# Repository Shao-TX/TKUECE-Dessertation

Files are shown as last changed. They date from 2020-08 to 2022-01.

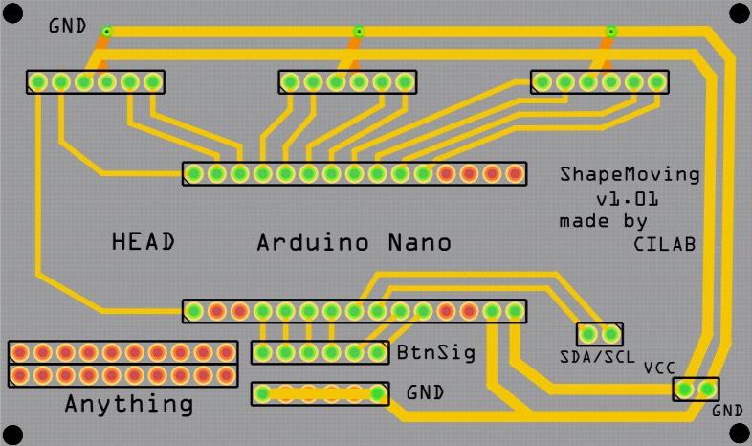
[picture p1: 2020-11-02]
hardware/PCB/Image/PCB_Image.jpg

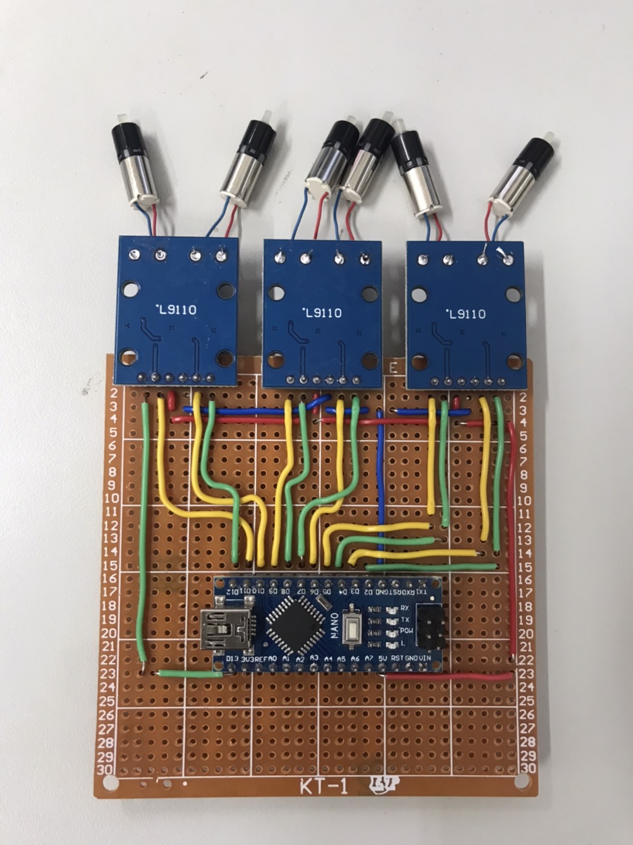
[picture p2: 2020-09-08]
images/Single_layer.jpg

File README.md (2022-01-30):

# TKUECE-Dissertation : Design of three-dimensional shape simulation device combined with tactile feedback

此裝置使用許多以3D列印製作的柱體和螺桿，利用外框將柱體固定，在以馬達轉動以達成將柱體上下移動的效果。我們使用Raspberry Pi作為I2C的Master對Arduino發送資料，使柱體上升或者下降，可以依此功能將柱體上升成指定形狀，和使用者互動、給予回饋。

## Hardware

### Device Appearance
Device Appearance

### Components

|Name|Quentity|Value|
|:---:|:----:|:----:|
|Capacitor|6|10uF|
|[TTMotor](https://reurl.cc/EzaZDv)|36|6mm , 1:25|
|[Limit Switch](https://reurl.cc/v18gXe)|36|2A , 125V|
|[Arduino Nano v3.1](https://reurl.cc/Xk9l90)|6|~|
|[Raspberry Pi 4](https://reurl.cc/GrlbRG)|1|~|

### PCB
PCB

## Software

### Run the code :

1. Python
2. C

### UI design:

1. Pyqt5
Pyqt5

## Result
[Video](https://youtu.be/8OqGQHrQrDk)

## Reference
[ShapeShifting](http://shape.stanford.edu/research/shapeShift/)

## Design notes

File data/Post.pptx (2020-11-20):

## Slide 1

結合觸覺回饋之立體形狀模擬裝置設計

周建興教授

沈奕辰、邵才獻

研究動機與目的
在觸覺回饋的領域中，一直都有人在研究都在能夠模擬所有物體的裝置，然而受限於技術及想法，這並不是一項容易的挑戰，許多人都對此做過研究，包括超聲波、手指力回饋等，也有台灣大學的專案利用大型充氣方格實現類似於Minecraft的場景，而其中有一項就是利用小型柱體上下移動，以高低差模擬物體的裝置 ，我們認為這是可行性最高且最能有效模擬物體狀態的方式，所以選擇以此來進行研究。

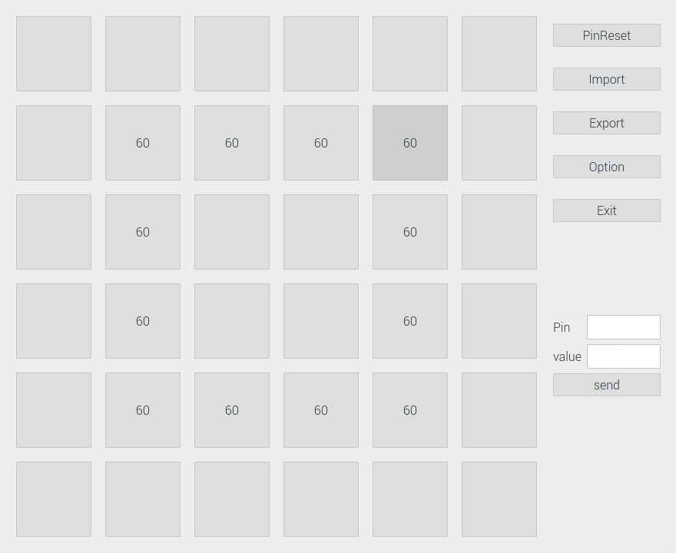
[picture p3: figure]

硬體設計
(圖4)為最初之3D設計草稿，原先我們預期做8*8的裝置，受限於成本及難易度，我們將裝置改為6*6，並做了一些調整，如馬達驅動板改為用焊接的而非用夾的以及Arduino板的位置。

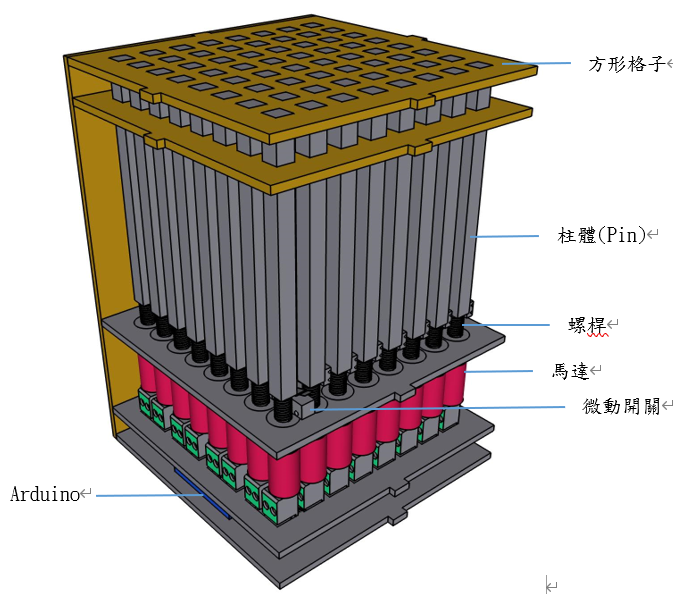
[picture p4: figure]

圖4.硬體設計圖

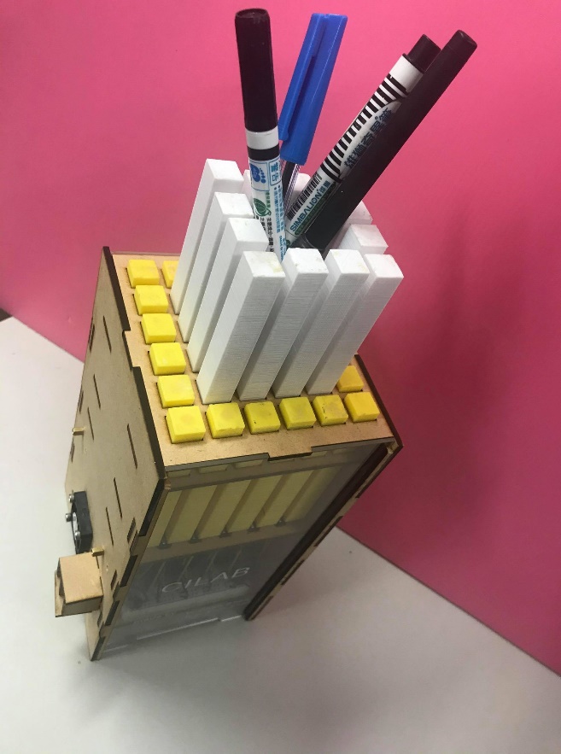
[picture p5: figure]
未提供說明。

圖1.裝置實際效果

圖2.軟體控制示意圖

系統架構
如系統架構圖(圖5)所示，為了使得柱體能夠上下移動，馬達帶動螺桿旋轉時，柱體會跟著轉動，因此我們將柱體用雷射切割的方形格子框住，所以當螺桿旋轉時，柱體不會跟著轉動，而是因為摩擦力而上下移動，在配合上下移動的時間，再將秒數換算成距離，便能夠控制所有的柱體的位置。

圖3.GitHub Repository QR code

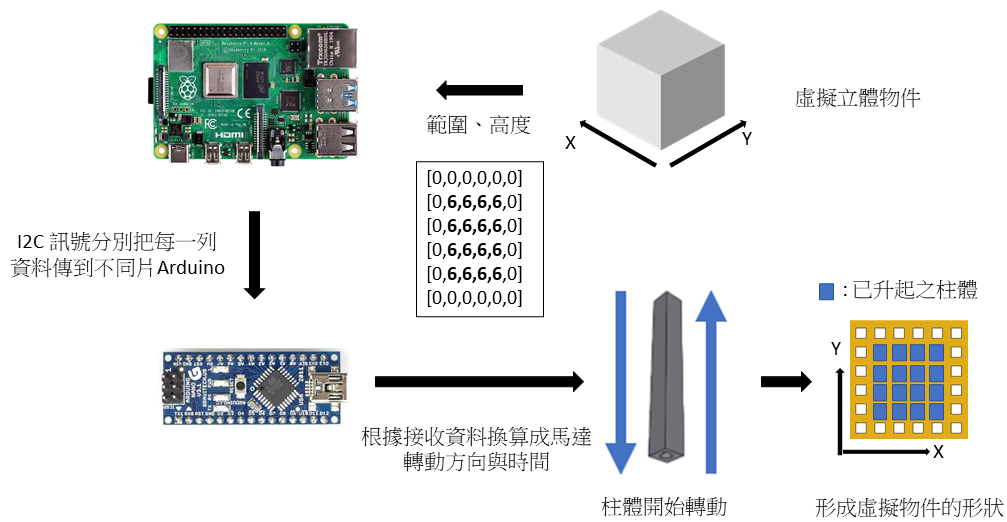
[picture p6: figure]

圖5.系統架構圖

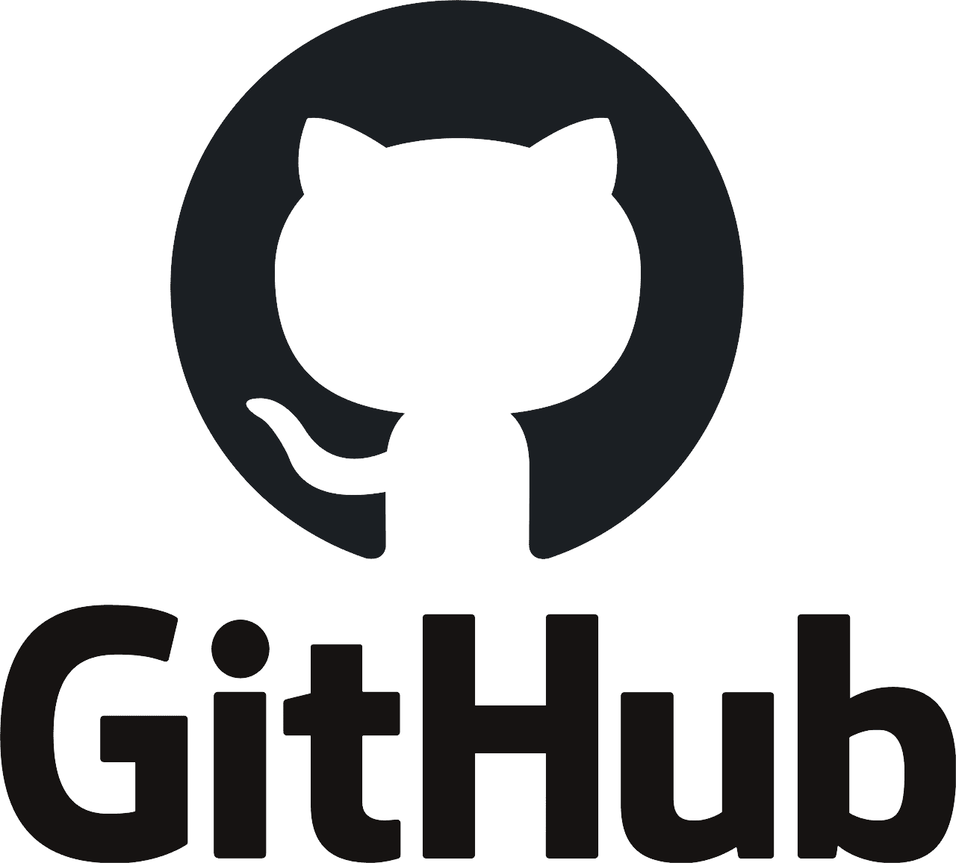
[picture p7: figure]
GitHub logo and symbol, meaning, history, PNG
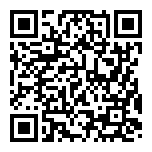
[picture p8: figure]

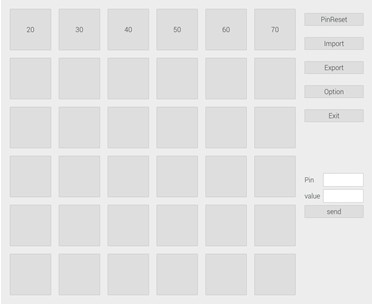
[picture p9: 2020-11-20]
images/Pyqt5.jpg

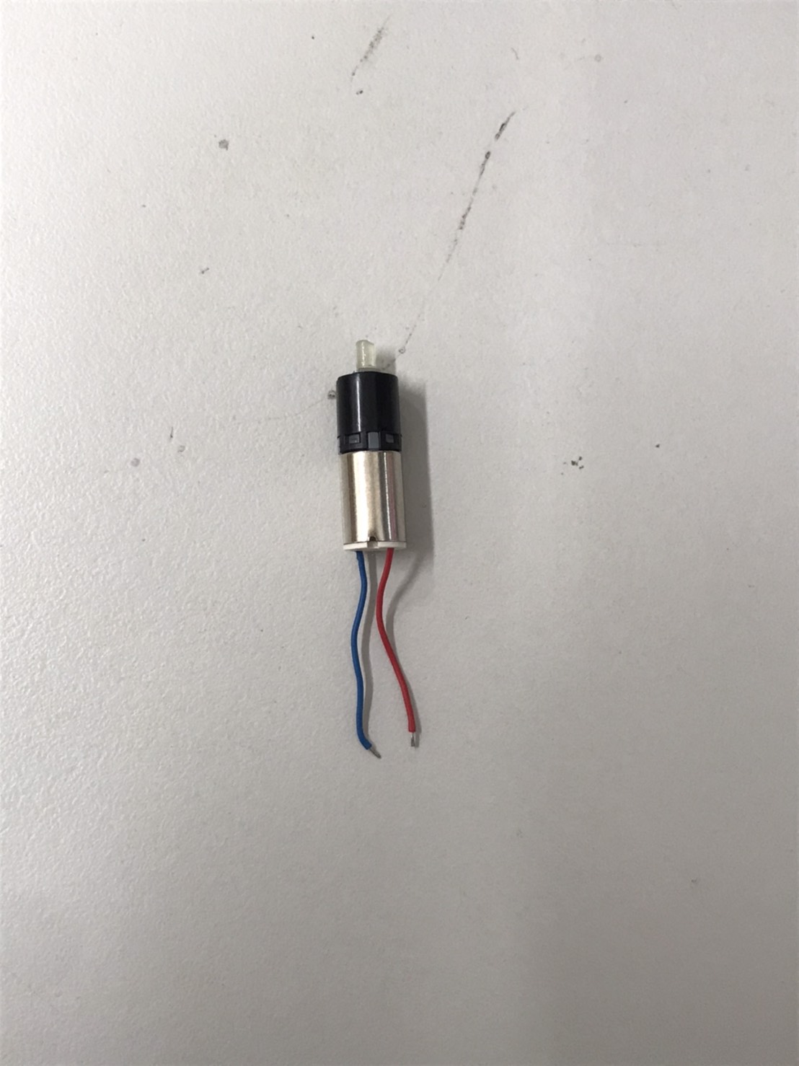
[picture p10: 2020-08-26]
images/TTmotor.jpg

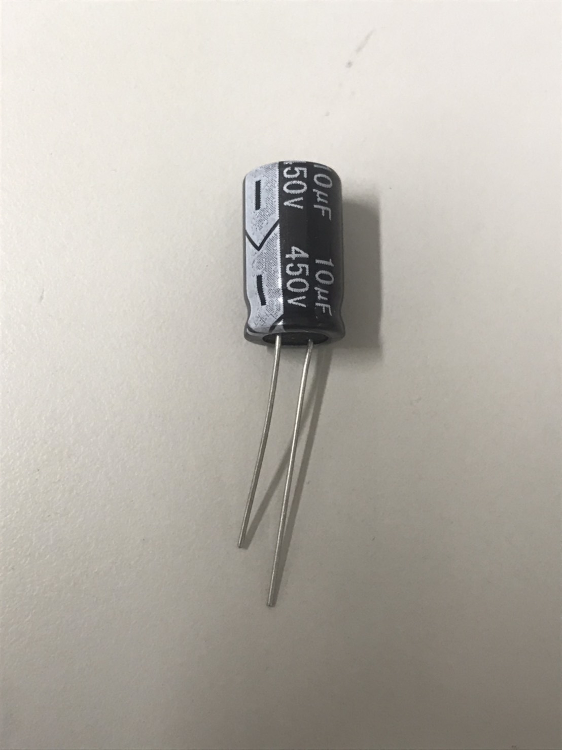
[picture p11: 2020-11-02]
images/Capacitor.jpg

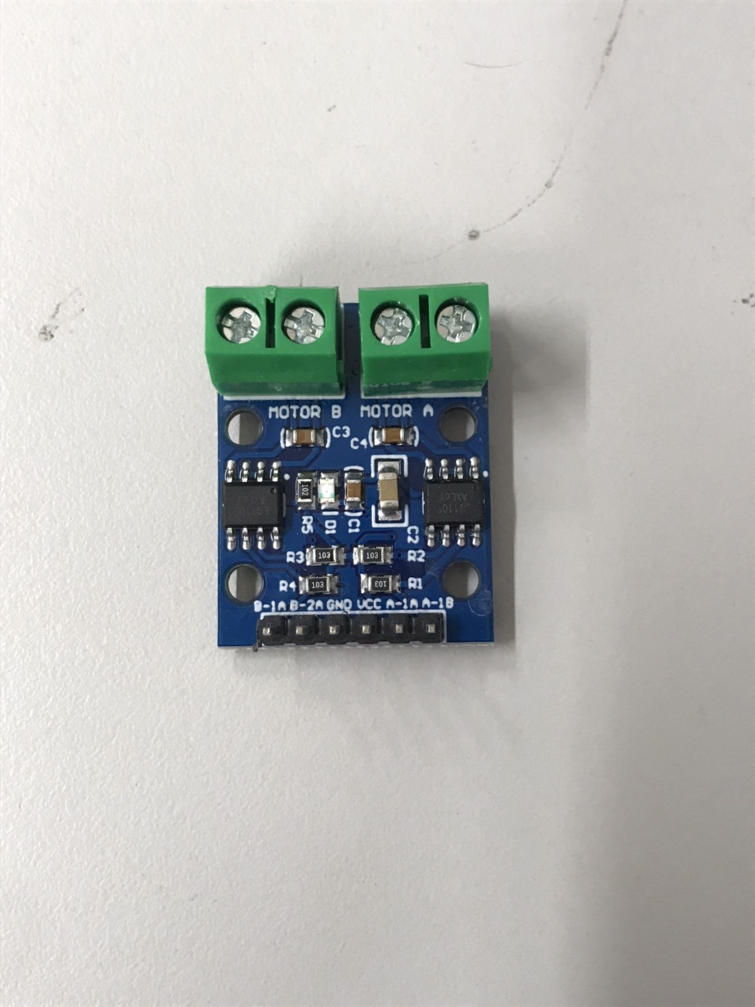
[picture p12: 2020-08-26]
images/motor_module.jpg

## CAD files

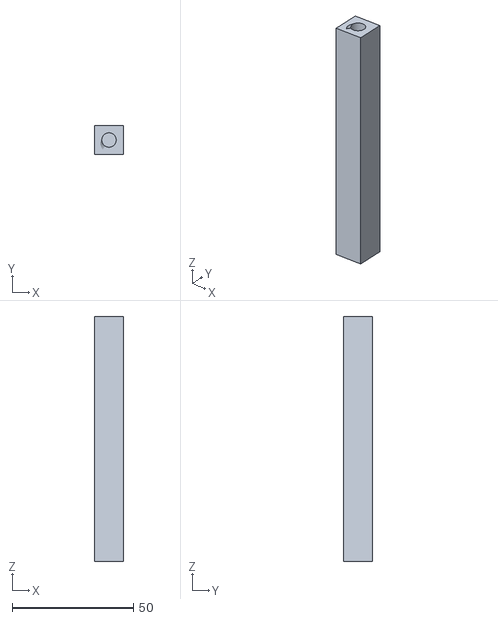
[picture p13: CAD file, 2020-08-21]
hardware/Pin/final_pin.stl
12.0 x 12.0 x 101.0

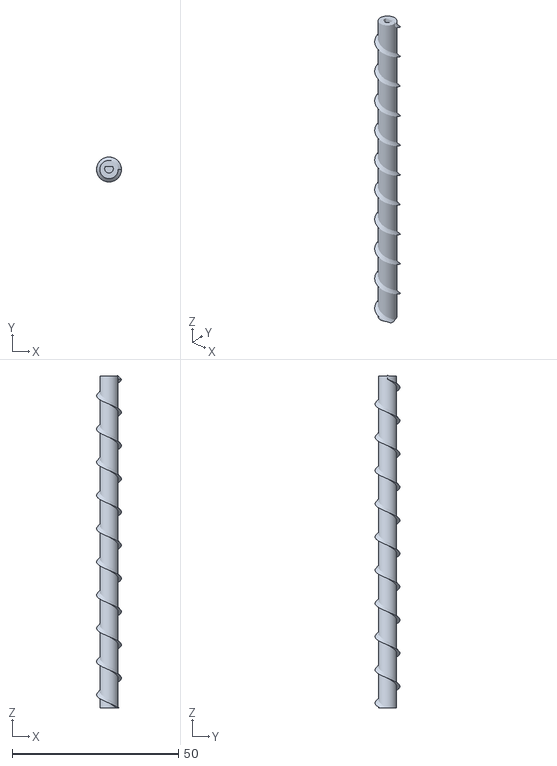
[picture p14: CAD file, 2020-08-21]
hardware/Pin/final_screw.stl
7.50 x 7.50 x 100.2

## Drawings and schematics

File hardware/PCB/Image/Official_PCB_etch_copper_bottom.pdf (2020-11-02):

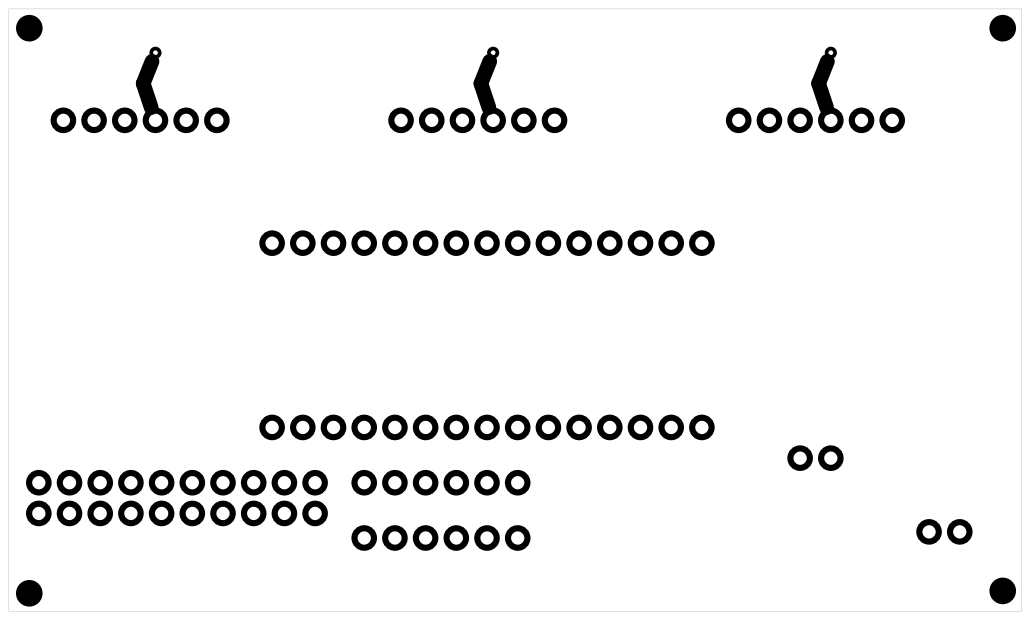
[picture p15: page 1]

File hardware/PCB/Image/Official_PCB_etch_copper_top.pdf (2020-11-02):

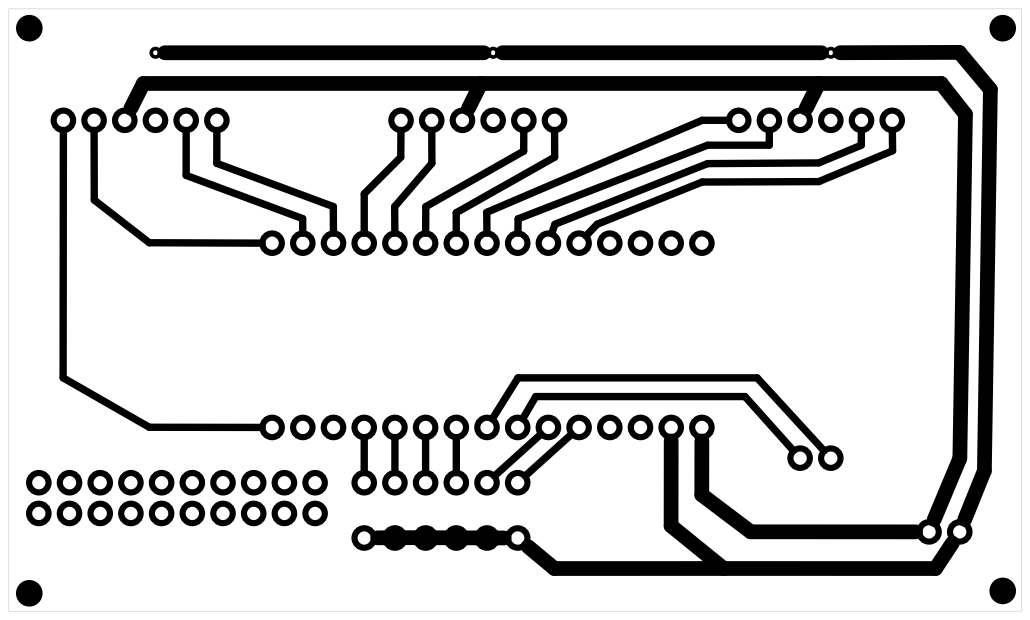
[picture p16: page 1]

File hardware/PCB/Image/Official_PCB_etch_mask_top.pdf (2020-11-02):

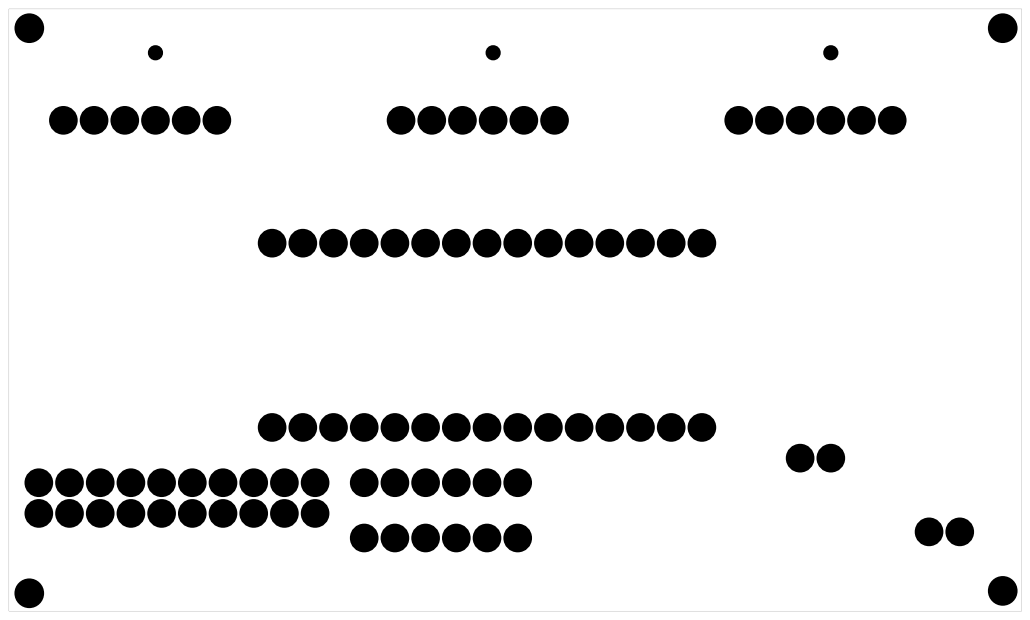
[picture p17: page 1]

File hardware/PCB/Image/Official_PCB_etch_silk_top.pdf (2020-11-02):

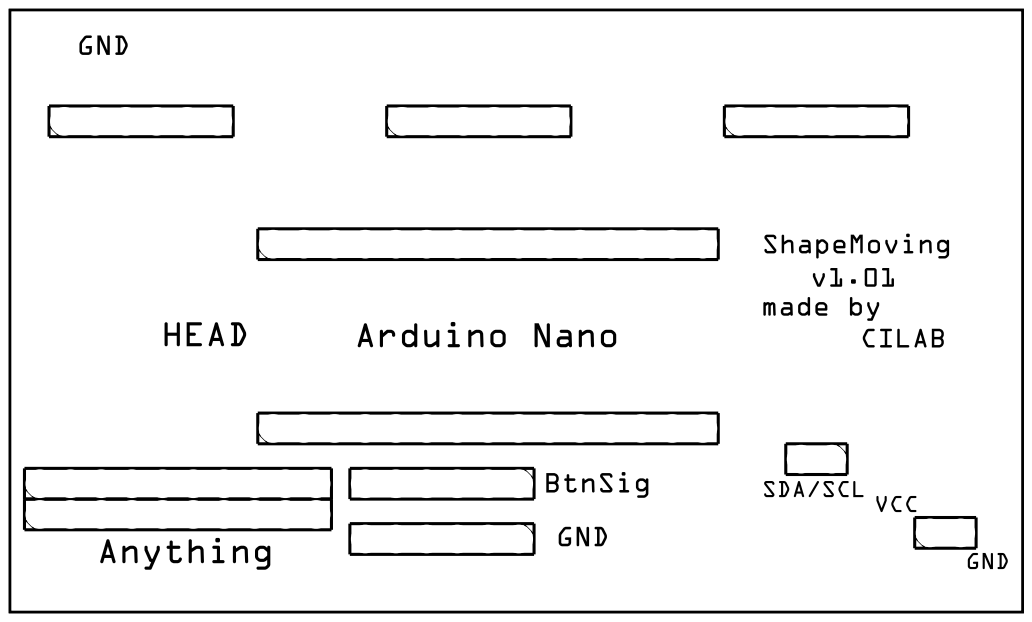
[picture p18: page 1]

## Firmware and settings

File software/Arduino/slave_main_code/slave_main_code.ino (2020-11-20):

#include <Wire.h>
#include <EEPROM.h>


#define SLAVE_ADDRESS 0x08
#define MOTOR_NUM 6
#define POS_MEM 0x00
#define HEI_MEM 0x06


int motorPin[MOTOR_NUM*2]  = {13,12,11,10,9,8,7,6,5,4,3,2};
int limitSwitchPin[MOTOR_NUM] = {A0,A1,A2,A3,A6,A7};
int receive_Data[MOTOR_NUM] = {0}; 

typedef struct{
  int mpA,mpB;
  int lsp;
  byte start;
  int countDown;
  int nowTime;
  byte reset;
  int pos;
}Pin;


static float ms_per_mm = 5.285;
//static float ms_per_mm = 7;
static int btnGap = 100;
int moving;
int testData[MOTOR_NUM] = {30,30,30,30,30,30};
Pin pin[MOTOR_NUM];
int getData;
int standby=0;

void setup() 
{
  Serial.begin(9600);
  Serial.println("I2C setup...");
  Wire.begin(SLAVE_ADDRESS);
  Wire.onReceive(receiveData);
  Wire.onRequest(sendData);
  Serial.println("I2C success...");
  //delay(1000);
  
  for(int i=0;i<MOTOR_NUM;i++){
    pin[i].mpA = motorPin[i*2];
    pinMode(pin[i].mpA,OUTPUT);
    digitalWrite(pin[i].mpA,LOW);
    pin[i].mpB = motorPin[i*2 + 1];
    pinMode(pin[i].mpB,OUTPUT);
    digitalWrite(pin[i].mpB,LOW);
    pin[i].lsp = limitSwitchPin[i];
    pinMode(pin[i].lsp,INPUT_PULLUP);
    pin[i].reset=0;
  }

  int i=0;
  while(1){
    pinTest(i%6);
    i++;
  }
  
  motorReset();
  
  getData=0;
  Serial.println("setup end");
  standby = 1;
}


int time_stamp,time_stamp2;
int use_time;


void loop(){
  /*
  for(int i=0;i<MOTOR_NUM;i++){
    Serial.print("P");
    Serial.print(i);
    Serial.print(" : ");
    Serial.print(analogRead(pin[i].lsp));
  }
  
  Serial.print('\n');
  */
  if(getData){
    //Serial.println("getData");
    for(int i=0;i<MOTOR_NUM;i++){
      testData[i]=EEPROM.read(POS_MEM+i);
    }
    new_motorMove(testData);
    getData=0;
  }
  
  //pinTest(5);
}

void pinTest(int p){
  //up down
  int T = 800;
  Move(pin[p],1);
  delay(T);
  Stop(pin[p]);
  delay(T);
  Move(pin[p],0);
  delay(T);
  Stop(pin[p]);
  delay(T);
  
}

void receiveData(int bytecount)
{
  Wire.read();
  for(int i=0;Wire.available()&&i<MOTOR_NUM;i++){

    EEPROM.write(POS_MEM+i,Wire.read());
    
    getData=1;
  }
  
}

void sendData()
{
  for(int i=0;i<MOTOR_NUM;i++){
    Wire.write(EEPROM.read(HEI_MEM+i));
  }
}

int lspCheck(){
  for(int i=0;i<MOTOR_NUM;i++){
    if(analogRead(pin[i].lsp)<btnGap){
      //有按下去
      pin[i].reset=1;
      continue;
    }else{
      if(pin[i].reset){
        continue;
      }
      return 0;
    }
  }
  return 1;
}

void motorReset(){
  int val;
  Serial.println("reset start...");
  delay(500);
  while(!lspCheck()){
    
    for(int i=0;i<MOTOR_NUM;i++){
      if((val=analogRead(pin[i].lsp))<btnGap){
        Stop(pin[i]);
        pin[i].reset=1;
      }else{
        if(!(pin[i].reset)){
          Move(pin[i],0);
        }
      }
      
      Serial.print(i);
      Serial.print(" : ");
      Serial.print(val);
      Serial.print(", ");
      Serial.print(pin[i].reset);
      Serial.print(", ");
      
    }
    Serial.println(" ");
  }
  
  for(int i=0;i<MOTOR_NUM;i++){
    Stop(pin[i]);
    pin[i].reset=0;
    pin[i].pos=0;
    EEPROM.write(HEI_MEM+i,pin[i].pos);
  }
  
  Serial.println("reset end...");
}

void singleMotorReset(Pin pin){
  while(analogRead(pin.lsp)>btnGap) Move(pin,0);
  Stop(pin);
}


void motorMove(int *distance){
  
  //歸位
  motorReset();

  //計算要上升的距離時間
  // 70mm 370ms -> 1mm 5.285ms

  for(int i=0;i<MOTOR_NUM;i++){
    if(distance[i]==0){
      continue;
    }
    Move(pin[i],1);
    delay(distance[i]*ms_per_mm);
    Stop(pin[i]);
  }

}

void new_motorMove(int *distance){
  for(int i=0;i<MOTOR_NUM;i++){

    if(distance[i]==0 && analogRead(pin[i].lsp)>btnGap){
      //singleMotorReset(pin[i]);
    }else if(pin[i].pos>distance[i]){
      Move(pin[i],0);
      delay((pin[i].pos-distance[i])*ms_per_mm);
      Stop(pin[i]);
    }else if((pin[i].pos<distance[i])*ms_per_mm){
      Move(pin[i],1);
      delay((distance[i]-pin[i].pos)*ms_per_mm);
      Stop(pin[i]);
    }else{
      continue;
    }
    pin[i].pos=distance[i];
    EEPROM.write(HEI_MEM+i,pin[i].pos);
  }
}

void Move(Pin input,int way){
  moving=1;
  if(way==0){
    digitalWrite(input.mpA,HIGH);
    digitalWrite(input.mpB,LOW);
  }else{
    digitalWrite(input.mpB,HIGH);
    digitalWrite(input.mpA,LOW);
  }
}

void Stop(Pin input){
  moving=0;
  digitalWrite(input.mpA,LOW);
  digitalWrite(input.mpB,LOW);
}

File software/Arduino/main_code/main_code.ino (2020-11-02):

#define MOTOR_NUM 6

struct Motor{
  byte A,B,LS;
};

Motor motor[MOTOR_NUM];
byte motor_pins[MOTOR_NUM*2] = {13,12,11,10,9,8,7,6,5,4,3,2};
byte motor_limitSwitch[MOTOR_NUM] = {A0,A1,A2,A3,A6,A7};
int control = 0;

void setup(){
  //pinMode(A0,INPUT_PULLUP); // limited switch
  // put your setup code here, to run once:
  for(int i=0;i<MOTOR_NUM;i++){
    motor[i].A = motor_pins[i*2];
    motor[i].B = motor_pins[i*2+1];
    motor[i].LS = motor_limitSwitch[i];
    pinMode(motor[i].A,OUTPUT);
    pinMode(motor[i].B,OUTPUT);
    pinMode(motor[i].LS,INPUT_PULLUP);
    digitalWrite(motor[i].A,LOW);
    digitalWrite(motor[i].B,LOW);   
  }
  Serial.begin(9600); 
}

void loop() {
  Serial.println("connected!");
  up(control);
  delay(300);
  stop_(control);
  delay(300);
  down(control);
  delay(300);
  stop_(control);
  delay(300);
  control++;
  if(control==6){
    control=0;
  }
}

void up(byte index){
  digitalWrite(motor[index].A,HIGH);
  digitalWrite(motor[index].B,LOW);
}

void down(byte index){
  digitalWrite(motor[index].A,LOW);
  digitalWrite(motor[index].B,HIGH);
}


void reset(byte index){
  // limited switch
  while(!digitalRead(motor[index].LS)){
    down(index);
  }
  stop_(index);
}

void stop_(byte index){
  digitalWrite(motor[index].A,LOW);
  digitalWrite(motor[index].B,LOW);
}

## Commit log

2020-08-21 First create this github project
    [final_pin.stl, final_screw.stl, micro_expend.fzz]
2020-08-21 Add RaspberryPi file to software
2020-08-26 limited_switch 加註解
2020-08-26 修改 limited_switch 中判斷有無壓到微動的 print
2020-08-28 (1)limited_switch.ino:delay(250) to delay(100) (2)Sort the Laser_Cutting (3)Revise the PCB
    [micro_expend.fzz]
2020-09-06 加入nano擴充
    [nano_expend.fzz]
2020-09-06 修改nano擴充
    [nano_expend.fzz]
2020-09-08 新增組裝完的第一層圖片
2020-09-08 新增main_code
2020-09-11 修改文件位置
2020-09-14 新增PCB到images
2020-09-14 新增Fritzing資料夾
    [Official_PCB.fzz, micro_expend.fzz, nano_expend.fzz]
2020-09-14 新增Image資料夾
2020-09-14 資料夾排版微調
    [micro_expend.fzz, nano_expend.fzz]
2020-09-14 main_code改正式版
2020-10-08 修改雷切為正式版
2020-10-08 加入正式PCB
    [Official_PCB.fzz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]
2020-11-02 Make all files final
    [micro_expend.fzz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]
2020-11-05 加入README
2020-11-05 加入Pyqt5
2020-11-05 修改README
